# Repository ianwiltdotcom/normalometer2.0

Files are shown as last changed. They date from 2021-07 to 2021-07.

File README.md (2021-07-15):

# normalometer2.0
Brandywine High School Engineering devices for visualizing physics, redesigned from "version 1.0" by [Wagner Labs](http://www.wagnerlabs.net/NormalProject/) and designed with components by [Adafruit](https://adafruit.com).

The original device was created as a way for physics students to visualize the normal forces acting upon an apparatus, while encouraging students studying physics, engineering and computer science to experiment with the device.

"Version 2.0" updates the original design of the Normalometer with a more powerful processor, a better display, easier assembly, lower cost and host more advanced features, such as data logging. Running CircuitPython, it is designed to be even more hackable, allowing students to review the code and make changes on-the-fly.

## Assembly Instructions

See [ASSEMBLY.md](ASSEMBLY.md)

## Installation

Ensure the device is running CircuitPython 6.0 or newer. Clone this repository and copy it into `CIRCUITPY`.

## Contributing

If you found something that could be improved, feel free to submit an issue, or fork and make a pull request.

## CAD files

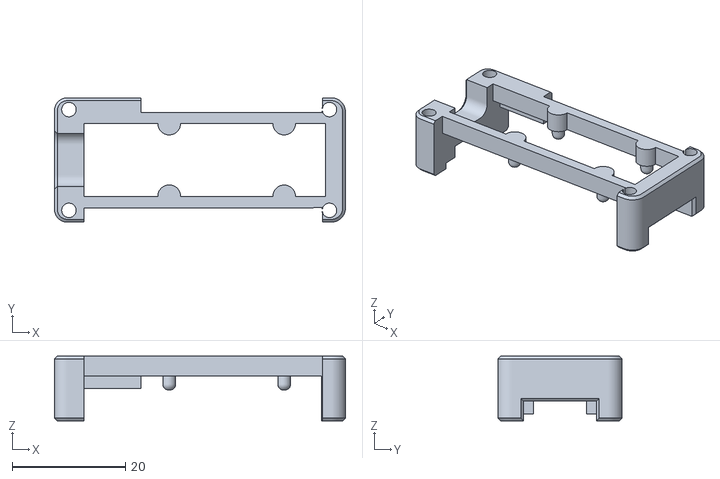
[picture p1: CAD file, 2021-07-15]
extras/BatteryHolder12mm USBC.stl
51.3 x 21.9 x 11.4

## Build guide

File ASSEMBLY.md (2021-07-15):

# Assembly
Want to build your own Normalometer 2.0? Follow these assembly instructions.

## Bill of Materials
Most parts can be ordered from [Adafruit](https://adafruit.com).

- [Adafruit Feather RP2040](https://www.adafruit.com/product/4884)
- [128x64 OLED FeatherWing](https://www.adafruit.com/product/4650)
- [Adafruit LIS3DH Accelerometer](https://www.adafruit.com/product/2809)
- [100mAh LiPoly Battery](https://www.adafruit.com/product/1570)
- [Adafruit Feather Female Headers](https://www.adafruit.com/product/2886)
- [JST-SH STEMMA QT cable (50mm)](https://www.adafruit.com/product/4399)
- 3D printed housing (see below)

## 3D Printing
The housing for the device can be 3D printed. The model is located under `extras/BatteryHolder12mm USBC.stl` Print in a sturdy material such as PLA with no supports and a higher (>50%) infill density.

## Assembly

1. Solder male headers onto the pins of the OLED FeatherWing, and solder the female headers onto the pins of the Feather RP2040.
2. Using the STEMMA QT cable, connect the accelerometer to the QT connector on the OLED FeatherWing.
3. Place the accelerometer face-up in the housing. Allow the cable to go through the "U" shaped hole on the side of the housing.
4. Place the battery between the female headers of the Feather RP2040, routing the wires around the side of the battery connector.
5. Place the housing on top of the battery, ensuring the accelerometer goes between the female headers.
6. Snap the screen on top of the female headers, making sure the STEMMA QT cable's slack is inside of the device.

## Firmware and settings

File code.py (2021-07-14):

import accelerometer
import buttoninputs
import screen
import time
import csvfile
import math

screen.showSplash(1)

usbConnected = False
try:
    csvfile.unlock()
except:
    usbConnected = True
    print("USB connected")

if not accelerometer.isConnected():
    print("Hisssss!\nNo accelerometer!\nCheck the cable!")
    screen.showNothing()
    while True:
        pass

screen.showMainMenu()

def rawDataViewLoop(length):
    accelList = []
    for i in range(length):
        accelList.append(0)
    mode = 1

    while True:
        if (mode == 1):
            accelList[length - 1] = accelerometer.getXAcceleration()
        if (mode == 2):
            accelList[length - 1] = accelerometer.getYAcceleration()
        if (mode == 4):
            accelList[length - 1] = accelerometer.getZAcceleration()
        j = 0
        for i in range(length - 1):
            accelList[j] = accelList[j + 1]
            j = j + 1
        screen.showGraph(accelList, mode, length)

        button = buttoninputs.nextButton()
        if (button):
            for i in range(length):
                accelList[i] = 0
            mode = button

def vectorLoop():
    while True:
        x = accelerometer.getXAcceleration() / 9.81
        y = -1 * accelerometer.getYAcceleration() / 9.81
        r = math.sqrt(math.pow(x, 2) + math.pow(y, 2))

        x1 = int((x + 1) * (128) / 2)
        #x1 = int((x + 1) * (64) / 2) + 32
        y1 = int((y + 1) * (64) / 2)
        #y1 = int((y + 1) * (128) / 2) - 32

        while (x1 > 0 and x1 < 128 and y1 > 0 and y1 < 64):
            x1 += (x1 > 64)
            x1 -= (x1 < 64)
            y1 += (y1 > 32)
            y1 -= (y1 < 32)
            if (x1 == 64 or y1 == 32):
                break

        screen.showVector(x1, y1, r)

def recordData():
    screen.countdown(3)
    datalist = []
    t = time.monotonic()
    dt = 0
    while (dt < recorderTime):
        datalist.append(dt)
        if (recorderMode & 1):
            datalist.append(accelerometer.getXAcceleration())
        if (recorderMode & 2):
            datalist.append(accelerometer.getYAcceleration())
        if (recorderMode & 4):
            datalist.append(accelerometer.getZAcceleration())
        dt = time.monotonic() - t
    screen.saveText(0, 0)
    savedFile = csvfile.saveFile(datalist, recorderMode)
    screen.saveText(1, savedFile)
    while True:
        pass

menuMode = 0 #Main Menu
recorderMode = 1
recorderTime = 1
sleepTime = time.monotonic()

while True:
    button = buttoninputs.nextButton()
    if (menuMode == 1):
        if (button == 1):
            recorderTime += 1
            screen.showRecorderMenu(recorderTime, recorderMode)
        if (button == 9):
            recorderTime = 1
            screen.showRecorderMenu(recorderTime, recorderMode)
        if (button == 2):
            if (recorderMode == 7):
                recorderMode = 1
            else:
                recorderMode += 1
            screen.showRecorderMenu(recorderTime, recorderMode)
        if (button == 4):
            recordData()

    if (menuMode == 0):
        if (button == 1):
            vectorLoop()
        if (button == 2):
            rawDataViewLoop(64)
        if (button == 10): #hold and release B
            rawDataViewLoop(128)
        if (button == 4):
            if (not usbConnected):
                screen.showRecorderMenu(recorderTime, recorderMode)
                menuMode = 1
            else:
                screen.errorText()
                time.sleep(3)
                screen.showMainMenu()
                sleepTime = time.monotonic()

    sleepCheck = time.monotonic() - sleepTime
    if (sleepCheck > 30 and menuMode == 0):
        print("30 seconds without input. Time to sleep.")
        screen.blankScreen()
        b = 0
        while (b == 0):
            b = buttoninputs.buttonState()
        print("Wake up!")
        screen.showMainMenu()
        sleepTime = time.monotonic()

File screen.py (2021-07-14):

import board
import displayio
import adafruit_displayio_sh1107
import time
import math

import terminalio
from adafruit_display_text import label
from adafruit_display_shapes import rect
from adafruit_display_shapes import line

displayio.release_displays()

i2c = board.I2C()
display_bus = displayio.I2CDisplay(i2c, device_address=0x3C)

WIDTH = 128
HEIGHT = 64

display = adafruit_displayio_sh1107.SH1107(display_bus, width=WIDTH, height=HEIGHT)
font = terminalio.FONT
display.auto_refresh = False

plotter = displayio.Group()
palette = displayio.Palette(2)
palette[0] = 0x000000
palette[1] = 0xFFFFFF
plotter.append(displayio.Group())
plot_label = label.Label(font, text=" ", y=8)
plotter.append(plot_label)

def errorText():
    error_group = displayio.Group()
    usb_label = label.Label(font, text="Can't save to disk", y=8)
    usb_label2 = label.Label(font, text="when USB is connected", y=18)
    usb_label3 = label.Label(font, text="Unplug, press reset", y=28)
    usb_label4 = label.Label(font, text="button and try again", y=38)
    error_group.append(usb_label)
    error_group.append(usb_label2)
    error_group.append(usb_label3)
    error_group.append(usb_label4)
    display.show(error_group)
    display.refresh()

def saveText(saved, saveNum):
    if (saved):
        saved_group = displayio.Group(scale=1)
        saved_label = label.Label(font, text="Saved to:", y=16, x=2)
        saved_label2 = label.Label(font, text="/records/record{}.csv".format(saveNum), y=26, x=2)
        saved_label3 = label.Label(font, text="Please press reset.", y=46, x=2)
        saved_group.append(saved_label2)
        saved_group.append(saved_label3)
    else:
        saved_group = displayio.Group(scale=2)
        saved_label = label.Label(font, text="Saving...", y=15, x=2)
    saved_group.append(saved_label)
    display.show(saved_group)
    display.refresh()

def countdown(t):
    countdown_group = displayio.Group(scale=3)
    number_label = label.Label(font, text=str(t), y=10, x=20)
    countdown_group.append(number_label)
    display.show(countdown_group)
    for i in range(t):
        display.refresh()
        t -= 1
        number_label.text = str(t)
        time.sleep(1)
    recording_group = displayio.Group(scale=2)
    recording_label = label.Label(font, text="Recording!", y=15, x=2)
    recording_group.append(recording_label)
    display.show(recording_group)
    display.refresh()

def showMainMenu():
    mainmenu_group = displayio.Group()
    title_label = label.Label(font, text="Normalometer 2.0", y=8, x=16)
    title_rect = rect.Rect(0, 0, 128, 18, outline=palette[1])
    label_a = label.Label(font, text="A: Normal Vectors", y=38)
    label_b = label.Label(font, text="B: Raw Data Viewer", y=48)
    label_c = label.Label(font, text="C: Recorder Mode", y=58)
    label_info = label.Label(font, text="<-- (Click a button)", y=24)
    mainmenu_group.append(label_info)
    mainmenu_group.append(title_label)
    mainmenu_group.append(title_rect)
    mainmenu_group.append(label_a)
    mainmenu_group.append(label_b)
    mainmenu_group.append(label_c)
    display.show(mainmenu_group)
    display.refresh()

def showRecorderMenu(time, mode):
    recordermenu_group = displayio.Group()
    title_label = label.Label(font, text="Recorder Mode", y=8, x=24)
    title_rect = rect.Rect(0, 0, 128, 18, outline=palette[1])
    label_info = label.Label(font, text=" ", y=24)
    label_a = label.Label(font, text="A: Record Time: " + str(time) + "s", y=38)
    bLabelText = "B: Columns [T"
    if (mode & 1):
        bLabelText += " X"
    if (mode & 2):
        bLabelText += " Y"
    if (mode & 4):
        bLabelText += " Z"
    bLabelText += "]"
    label_b = label.Label(font, text=bLabelText, y=48)
    label_c = label.Label(font, text="C: Start Recording", y=58)
    recordermenu_group.append(title_label)
    recordermenu_group.append(title_rect)
    recordermenu_group.append(label_a)
    recordermenu_group.append(label_b)
    recordermenu_group.append(label_c)
    recordermenu_group.append(label_info)
    display.show(recordermenu_group)
    display.refresh()

def showNothing():
    display.show(None)
    display.refresh()

def blankScreen():
    blankScreen_group = displayio.Group()
    blankScreen = rect.Rect(0, 0, 128, 64, fill=0x000000)
    blankScreen_group.append(blankScreen)
    display.show(blankScreen_group)
    display.refresh()

def showSplash(timeout):
    with open("/splash.bmp", "rb") as splashfile:
        bitmap = displayio.OnDiskBitmap(splashfile)
        tilegrid = displayio.TileGrid(bitmap, pixel_shader=displayio.ColorConverter())
        splash_group = displayio.Group()
        splash_group.append(tilegrid)
        display.show(splash_group)
        display.refresh()

        time.sleep(timeout)

def showVector(xval, yval, length):
    newLength = math.sqrt(math.pow(xval - 64, 2) + math.pow(yval - 32, 2)) * length
    try:
        slope = (yval - 32) / (xval - 64)
    except:
        slope = None
    print((xval, yval, slope, newLength))

    newXVal = xval
    newYVal = yval
    curLength = math.sqrt(math.pow(xval - newXVal, 2) + math.pow(yval - newYVal, 2))

    while (curLength < newLength):
        newXVal -= 1
        newYVal -= slope
        curLength = math.sqrt(math.pow(xval - newXVal, 2) + math.pow(yval - newYVal, 2))

    plotter[0] = line.Line(xval, yval, int(newXVal), int(newYVal), palette[1])

    display.show(plotter)
    display.refresh()


def showGraph(accelList, mode, length):
    if (mode == 1):
        plot_label.text = "X:"
    if (mode == 2):
        plot_label.text = "Y:"
    if (mode == 4):
        plot_label.text = "Z:"

    yValues = []
    for i in accelList:
        mapped = int((i + 10) * (64) / 20)
        yValues.append(mapped)

    yRange = max(yValues) - min(yValues) + 1

    plot = displayio.Bitmap(length, yRange, 2)
    plot.fill(0)

    for x in range(length):
        newMap = int((yValues[x]) * yRange / 64)
        try:
            plot[x, newMap] = 1
        except:
            pass

    plotter[0] = displayio.TileGrid(plot, pixel_shader=palette)
    plotter[0].y = int(32 - yRange/2)
    display.show(plotter)
    display.refresh()
